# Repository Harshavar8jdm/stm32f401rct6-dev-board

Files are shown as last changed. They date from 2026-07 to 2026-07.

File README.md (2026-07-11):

# STM32F401RCT6 Development Board

A compact development board built around the STM32F401RCT6 microcontroller. The design provides access to core peripherals via standard pin headers, incorporates dedicated power plane isolation for analog stability, and includes robust ESD protection for reliable USB communication. 

## Visuals

### Schematic Diagram
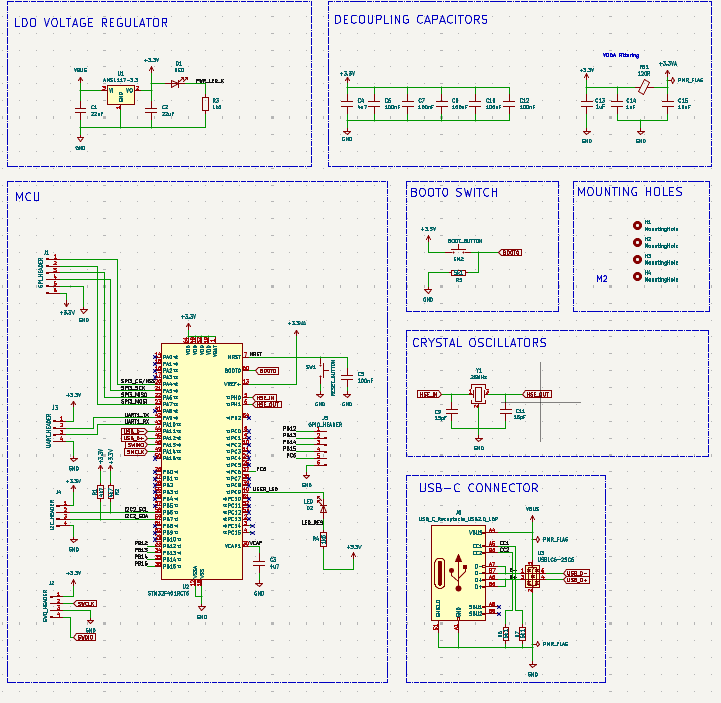
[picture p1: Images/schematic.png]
Schematic


### PCB Layout
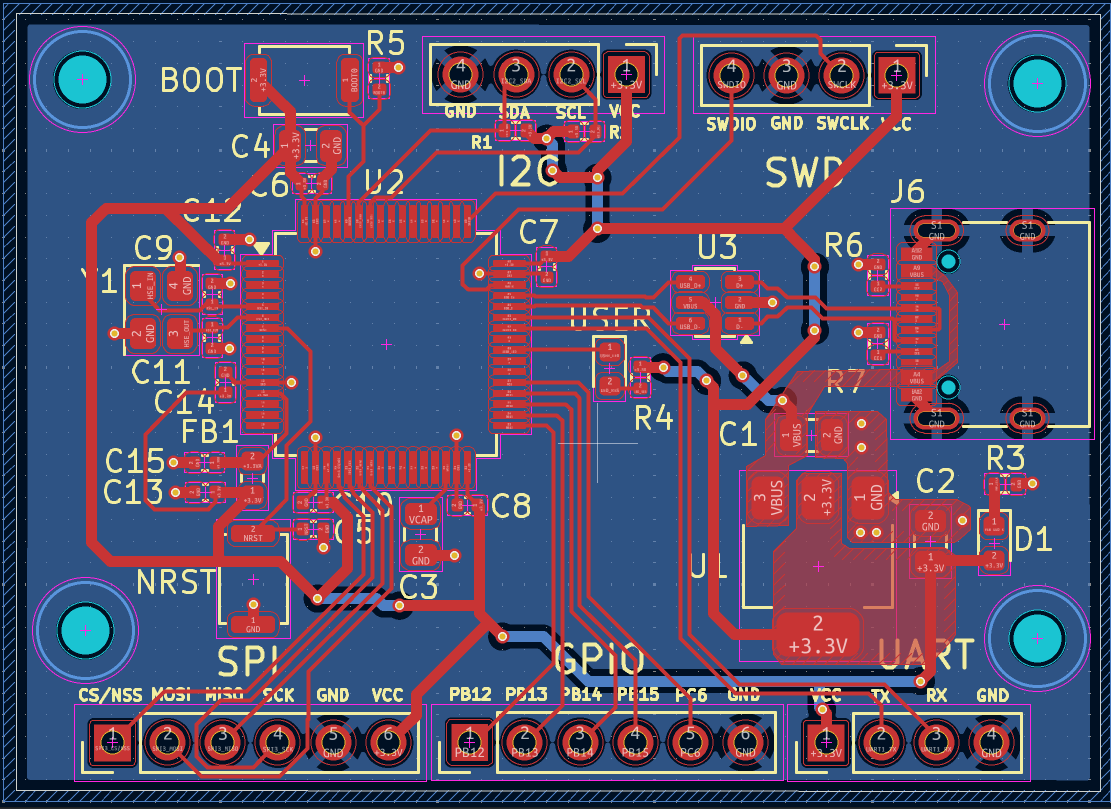
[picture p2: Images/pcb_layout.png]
PCB Layout


### 3D Renders
| Front View | Back View |
| :---: | :---: |
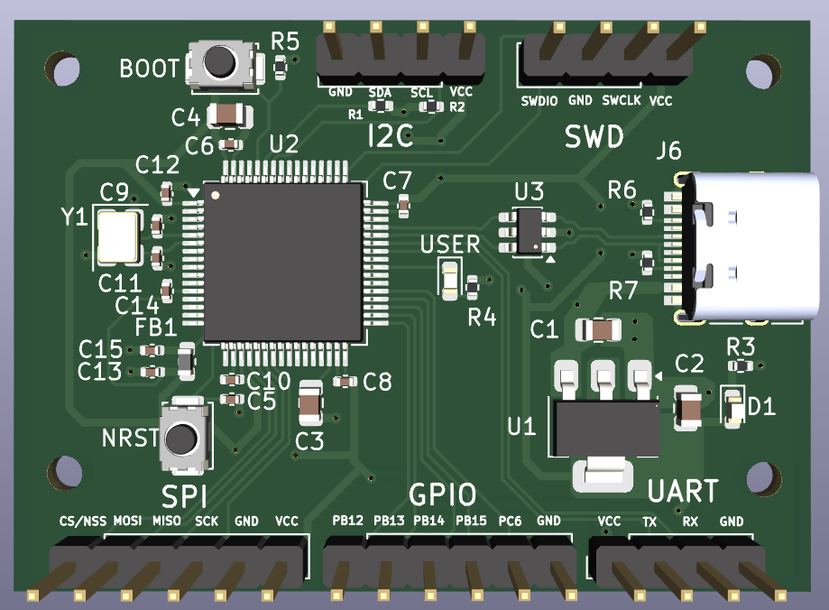
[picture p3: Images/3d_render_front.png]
3D Render Front
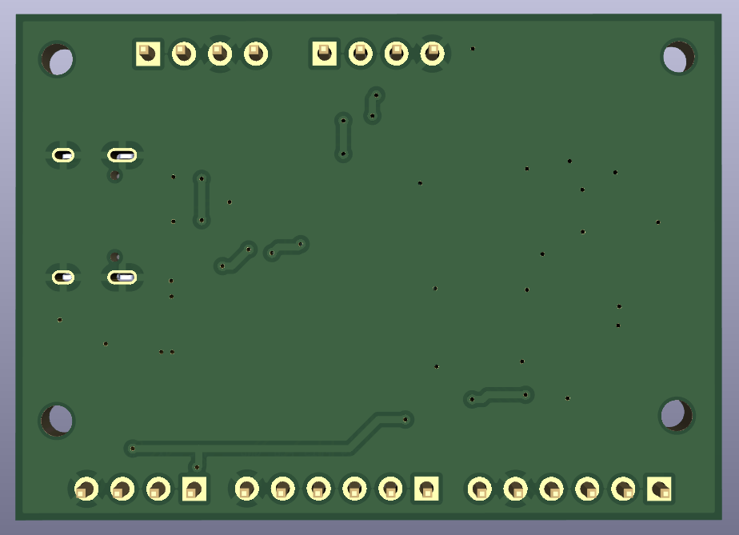
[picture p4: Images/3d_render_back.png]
3D Render Back
|  |  |

---

## Features

### 1. Core Processing & Clock System
* **Microcontroller:** STM32F401RCT6, 32-bit ARM Cortex-M4 core running up to 84 MHz.
* **High-Speed External (HSE) Clock:** $25\text{ MHz}$ crystal oscillator loop supplying the primary system and peripheral clock source.
* **Low-Speed External (LSE) Clock:** $32.768\text{ kHz}$ tuning-fork crystal providing timing for the internal Real-Time Clock (RTC).
* **Reset & Boot Controls:** Hardware reset circuitry utilizing an RC network connected to the `NRST` pin, paired with a dedicated physical push-button to pull `BOOT0` high for system bootloader entry.

### 2. Power Delivery & Noise Mitigation
* **Voltage Regulation:** AMS1117-3.3 Linear Voltage Regulator (LDO) stepping down a $5\text{V}$ input supply (via USB) to a regulated $+3.3\text{V}$ system rail, decoupled with dual $22\ \mu\text{F}$ bulk capacitors.
* **Digital Rail Decoupling:** Localized filtering network consisting of one $4.7\ \mu\text{F}$ bulk capacitor and five independent $100\text{ nF}$ capacitors dedicated to the $V_{DD}$ supply pins.
* **Analog Isolation ($+3.3\text{VA}$):** A $100\ \Omega$ (at $100\text{ MHz}$) ferrite bead creates a low-pass filter to separate the analog supply from digital switching noise, supported by dedicated $1\ \mu\text{F}$ and $100\text{ nF}$ capacitors.

### 3. Connectivity & Protection
* **USB-C Interface:** USB 2.0 downstream configuration over a physical USB-C connector using dual $5.1\text{ k}\Omega$ pulldown resistors on the `CC1` and `CC2` channels.
* **Transient Voltage Protection:** A USBLC6-2SC6 monolithic ESD protection diode array is placed directly on the `USB_D+` and `USB_D-` lines to safeguard internal transceivers against electrostatic discharge.
* **Peripheral Access:** Dedicated pin headers breaking out SPI (`SPI3`), I2C (`I2C2`), UART (`UART1`), Serial Wire Debug (`SWD`), and generic GPIOs.
* **System Status:** Physical LED indicators tracking power availability ($+3.3\text{V}$) and a user-programmable diagnostic LED linked to pin `PA0`.

---

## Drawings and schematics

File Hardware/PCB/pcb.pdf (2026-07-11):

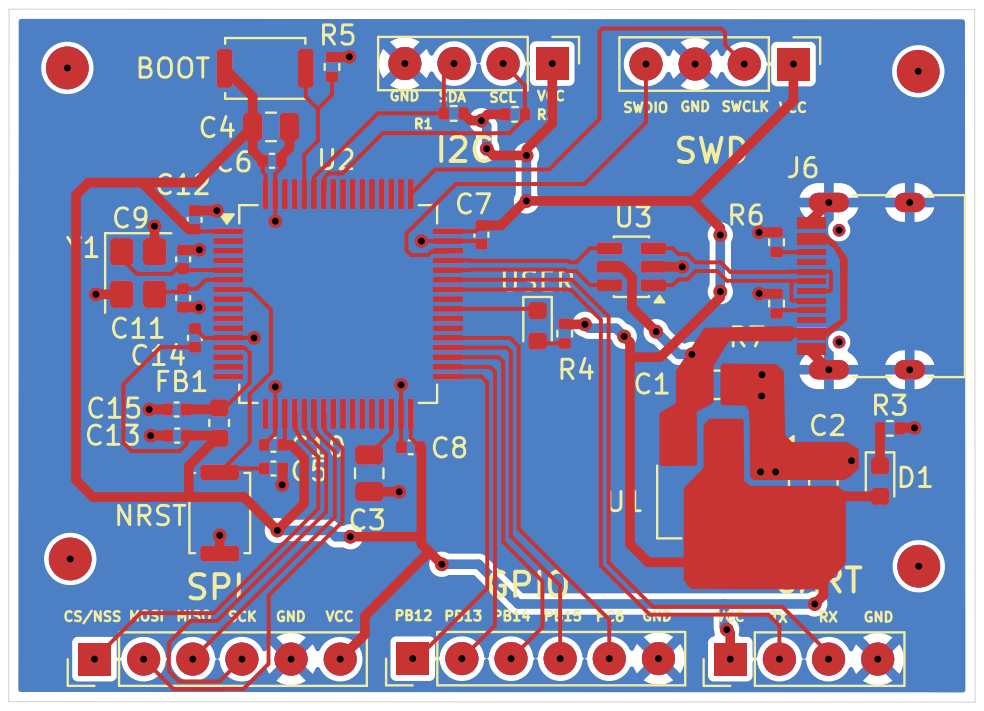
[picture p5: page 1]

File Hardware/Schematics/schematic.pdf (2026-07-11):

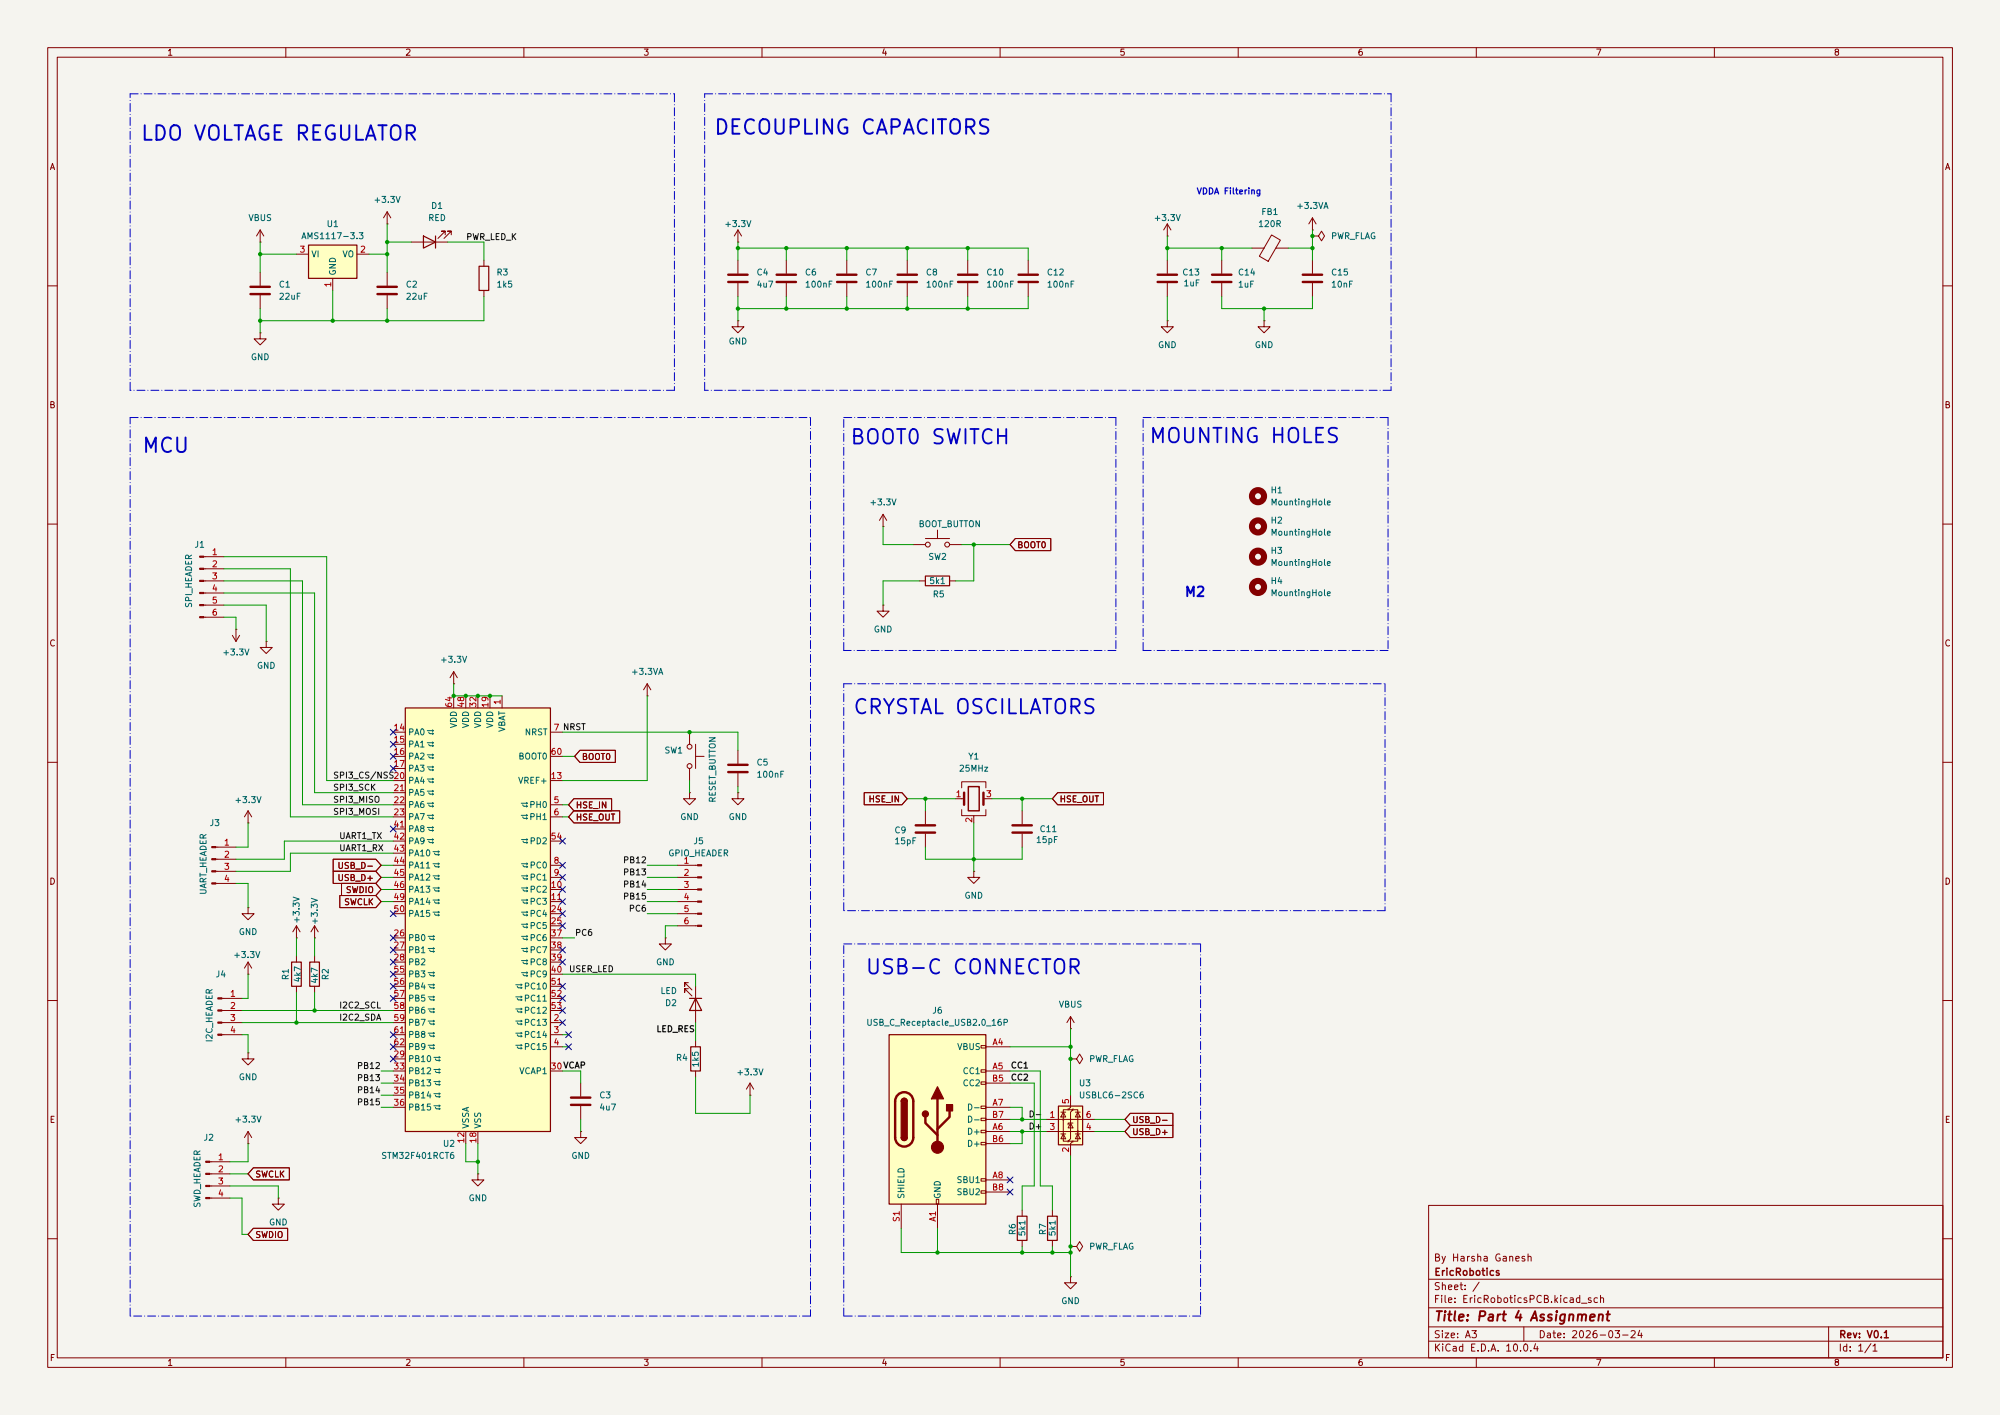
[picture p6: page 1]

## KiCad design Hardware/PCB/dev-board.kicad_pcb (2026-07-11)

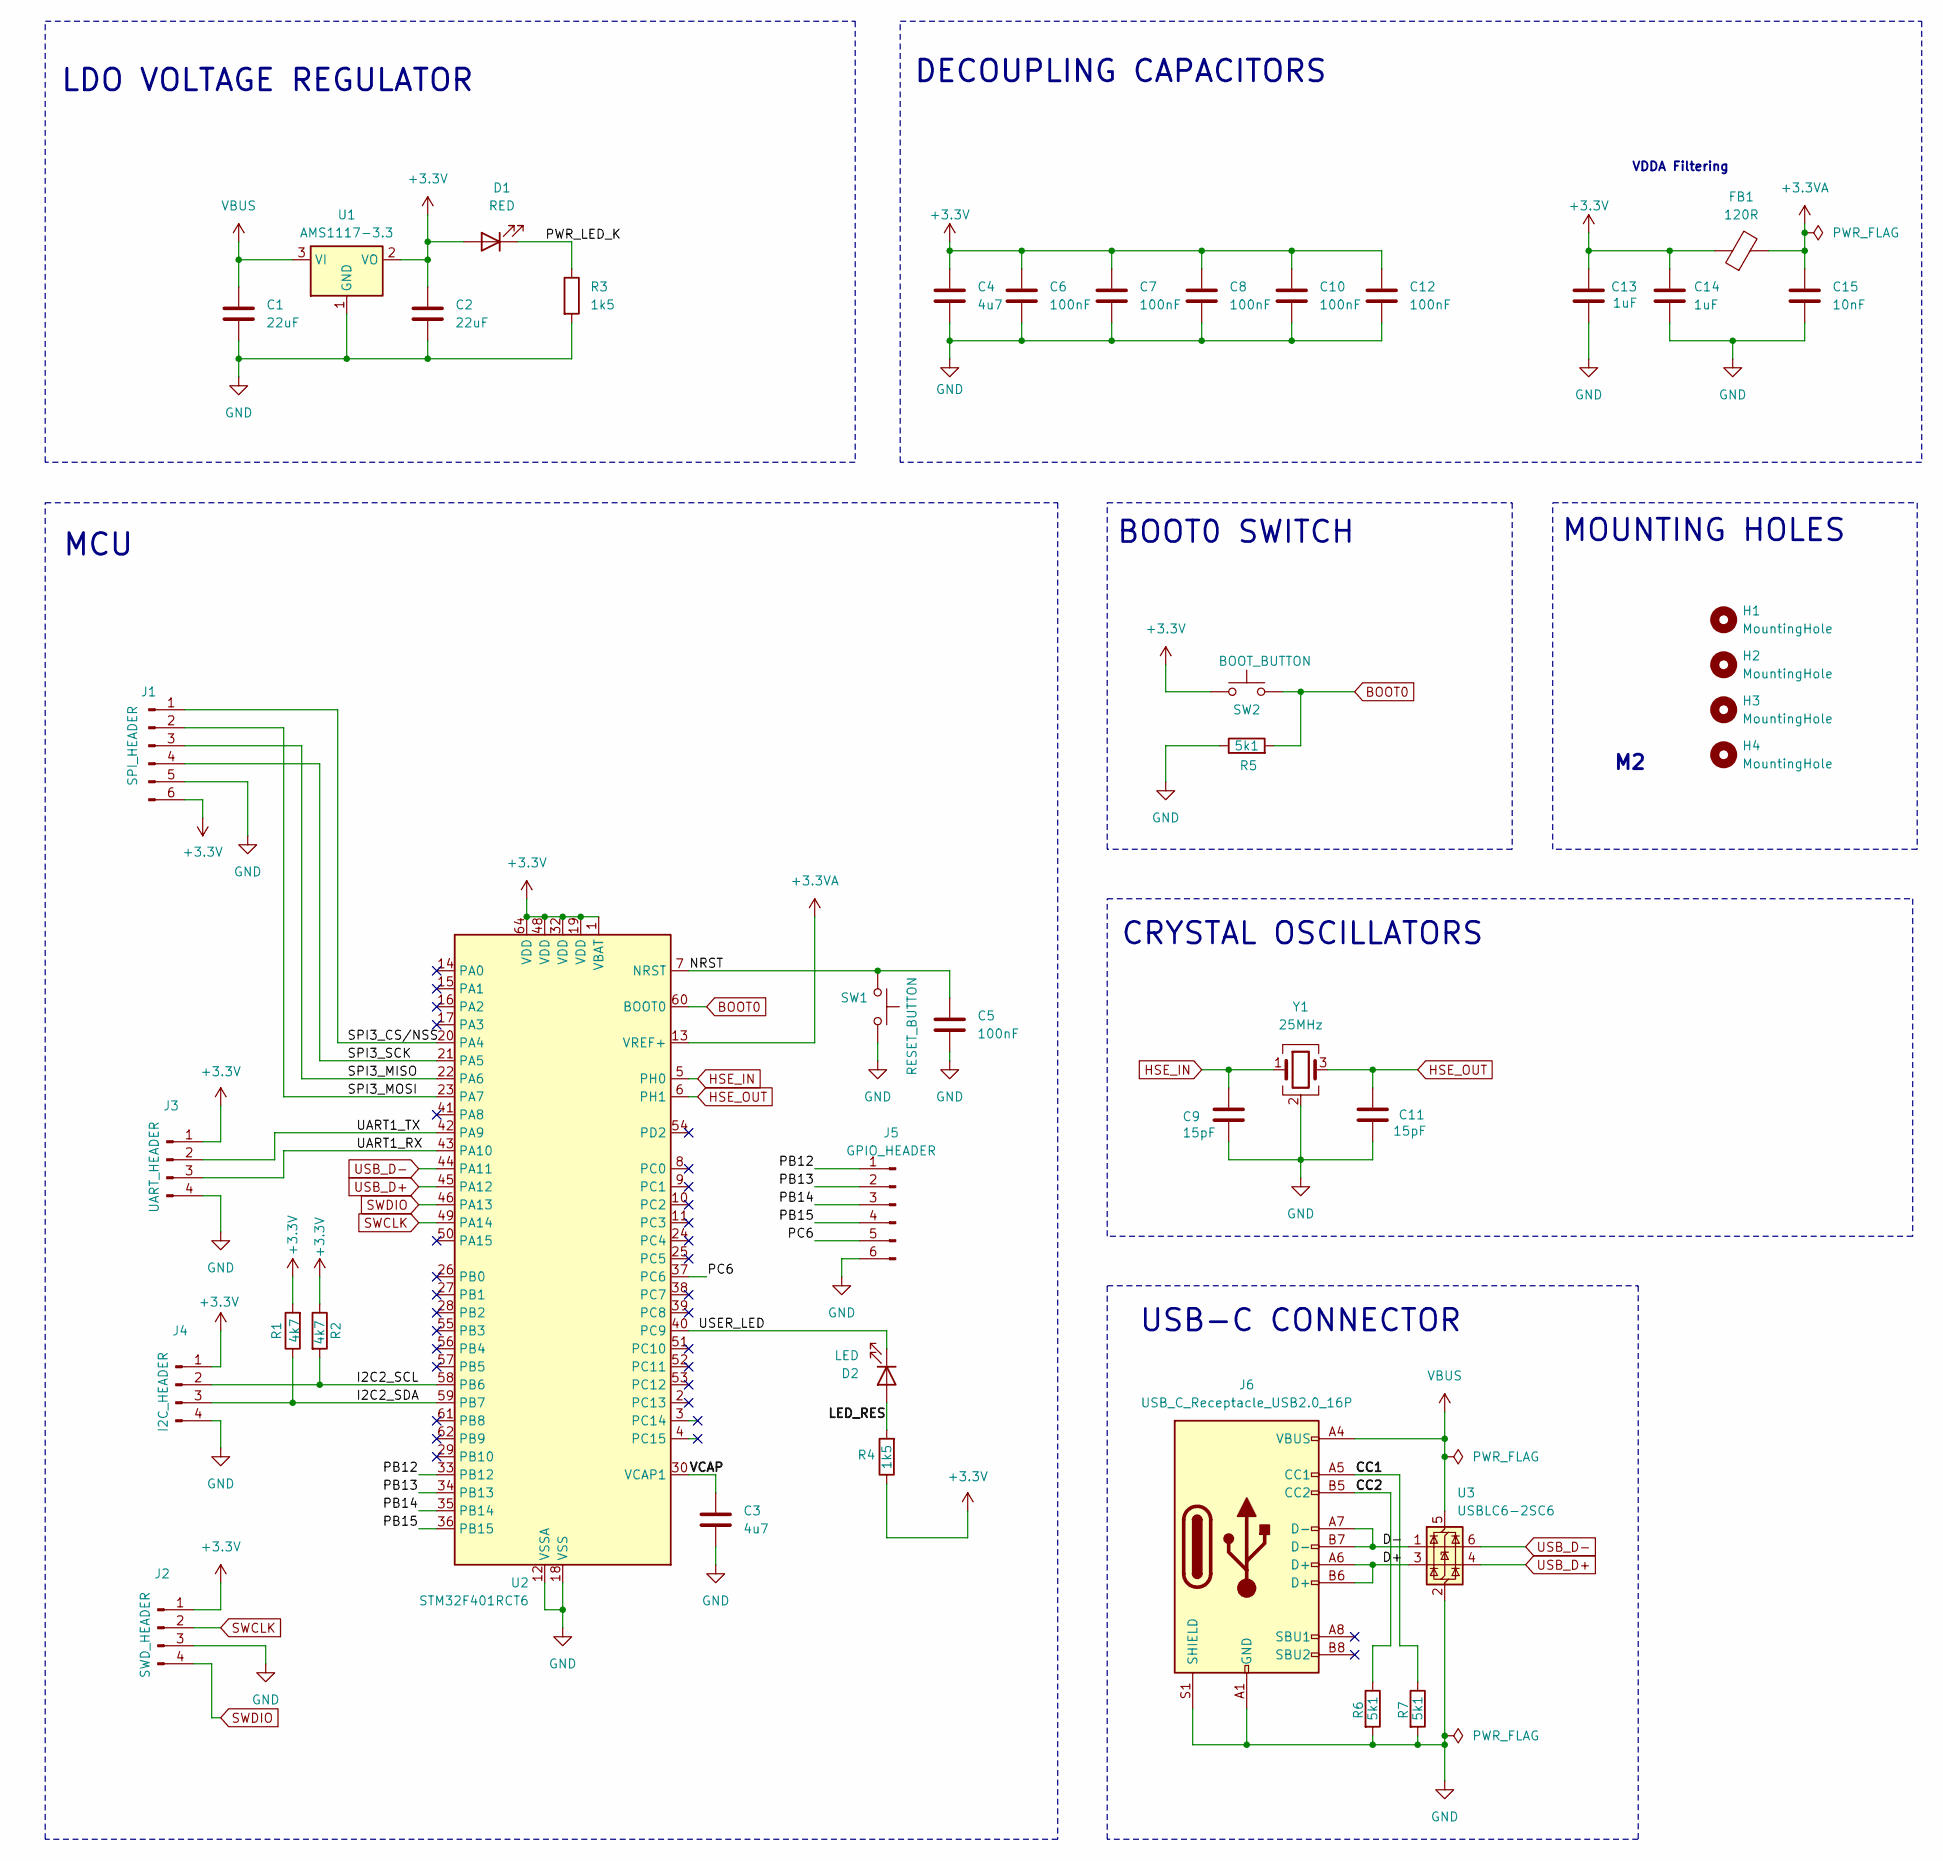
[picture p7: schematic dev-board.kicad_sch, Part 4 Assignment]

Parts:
C1, C2: 22uF; C_0805_2012Metric
C3, C4: 4u7; C_0805_2012Metric
C5, C6, C7, C8, C10, C12: 100nF; C_0402_1005Metric
C9, C11: 15pF; C_0402_1005Metric
C13, C14: 1uF; C_0402_1005Metric
C15: 10nF; C_0402_1005Metric
D1: RED; LED_0603_1608Metric
D2: LED; LED_0603_1608Metric
FB1: 120R; L_0603_1608Metric
H1, H2, H3, H4: MountingHole; MountingHole_2.2mm_M2
J1: SPI_HEADER; PinHeader_1x06_P2.54mm_Vertical
J2: SWD_HEADER; PinHeader_1x04_P2.54mm_Vertical
J3: UART_HEADER; PinHeader_1x04_P2.54mm_Vertical
J4: I2C_HEADER; PinHeader_1x04_P2.54mm_Vertical
J5: GPIO_HEADER; PinHeader_1x06_P2.54mm_Vertical
J6: USB_C_Receptacle_USB2.0_16P; USB_C_Receptacle_HRO_TYPE-C-31-M-12
R1, R2: 4k7; R_0402_1005Metric
R3, R4: 1k5; R_0402_1005Metric
R5, R6, R7: 5k1; R_0402_1005Metric
SW1: RESET_BUTTON; SW_Push_SPST_NO_Alps_SKRK
SW2: BOOT_BUTTON; SW_Push_SPST_NO_Alps_SKRK
U1: AMS1117-3.3; SOT-223-3_TabPin2
U2: STM32F401RCT6; LQFP-64_10x10mm_P0.5mm
U3: USBLC6-2SC6; SOT-23-6
Y1: 25MHz; Crystal_SMD_3225-4Pin_3.2x2.5mm

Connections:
+3.3V: C2.1, C4.1, C6.1, C7.1, C8.1, C10.1, C12.1, C13.1, C14.1, D1.2 (A), FB1.1, J1.6, J2.1, J3.1, J4.1, R1.2, R2.1, R4.1, SW2.2, U1.2 (VO), U2.1 (VBAT), U2.19 (VDD), U2.32 (VDD), U2.48 (VDD), U2.64 (VDD); also elsewhere on the board
+3.3VA: C15.1, FB1.2, U2.13 (VREF+)
/CC1: J6.A5 (CC1), R7.1
/CC2: J6.B5 (CC2), R6.1
/D+: J6.A6 (D+), J6.B6 (D+), U3.3 (I/O2)
/D-: J6.A7 (D-), J6.B7 (D-), U3.1 (I/O1)
/I2C2_SCL: J4.2, R2.2, U2.58 (PB6)
/I2C2_SDA: J4.3, R1.1, U2.59 (PB7)
/LED_RES: D2.2 (A), R4.2; also elsewhere on the board
/NRST: C5.1, SW1.2, U2.7 (NRST); also elsewhere on the board
/PB12: J5.1, U2.33 (PB12)
/PB13: J5.2, U2.34 (PB13)
/PB14: J5.3, U2.35 (PB14)
/PB15: J5.4, U2.36 (PB15)
/PC6: J5.5, U2.37 (PC6)
/PWR_LED_K: D1.1 (K), R3.1
/SPI3_CS/NSS: J1.1, U2.20 (PA4)
/SPI3_MISO: J1.3, U2.22 (PA6)
/SPI3_MOSI: J1.2, U2.23 (PA7)
/SPI3_SCK: J1.4, U2.21 (PA5)
/UART1_RX: J3.3, U2.43 (PA10)
/UART1_TX: J3.2, U2.42 (PA9)
/USER_LED: D2.1 (K), U2.40 (PC9); also elsewhere on the board
/VCAP: C3.1, U2.30 (VCAP1)
BOOT0: R5.2, SW2.1, U2.60 (BOOT0); also elsewhere on the board
GND: C1.2, C2.2, C3.2, C4.2, C5.2, C6.2, C7.2, C8.2, C9.2, C10.2, C11.2, C12.2, C13.2, C14.2, C15.2, J1.5, J2.3, J3.4, J4.4, J5.6, J6.A1 (GND), J6.A12 (GND), J6.B1 (GND), J6.B12 (GND), J6.S1 (SHIELD), R3.2, R5.1, R6.2, R7.2, SW1.1, U1.1 (GND), U2.12 (VSSA), U2.18 (VSS), U2.31 (VSS), U2.47 (VSS), U2.63 (VSS), U3.2 (GND), Y1.2 (G), Y1.4 (G); also elsewhere on the board
HSE_IN: C9.1, U2.5 (PH0), Y1.1
HSE_OUT: C11.1, U2.6 (PH1), Y1.3
SWCLK: J2.2, U2.49 (PA14)
SWDIO: J2.4, U2.46 (PA13)
USB_D+: U2.45 (PA12), U3.4 (I/O2)
USB_D-: U2.44 (PA11), U3.6 (I/O1)
VBUS: C1.1, J6.A4 (VBUS), J6.A9 (VBUS), J6.B4 (VBUS), J6.B9 (VBUS), U1.3 (VI), U3.5 (VBUS)

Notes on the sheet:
LDO VOLTAGE REGULATOR
MOUNTING HOLES
BOOT0 SWITCH
MCU
USB-C CONNECTOR
DECOUPLING CAPACITORS
CRYSTAL OSCILLATORS
VDDA Filtering

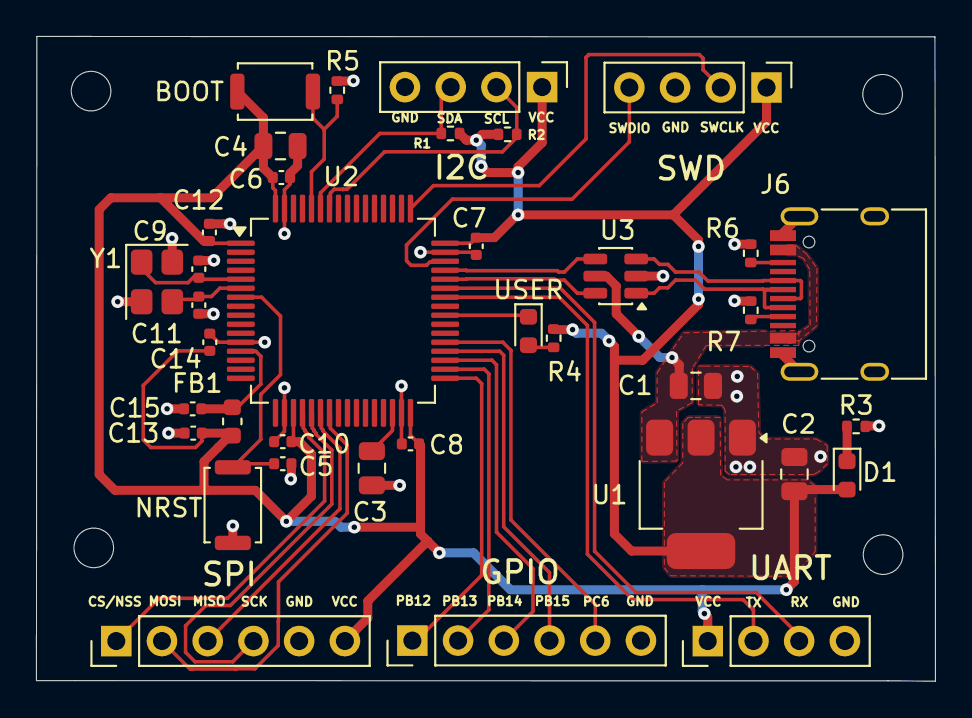
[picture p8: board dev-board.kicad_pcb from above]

Board: 2 copper layers, 49.9 x 35.8 mm, 41 parts (0 on the bottom side), 33 nets.

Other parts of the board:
BOOT: BOOT_BUTTON; SW_Push_SPST_NO_Alps_SKRK
NRST: RESET_BUTTON; SW_Push_SPST_NO_Alps_SKRK
USER: LED; LED_0603_1608Metric

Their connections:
+3.3V: BOOT.2; also elsewhere on the board
/LED_RES: USER.2 (A); also elsewhere on the board
/NRST: NRST.2; also elsewhere on the board
/USER_LED: USER.1 (K); also elsewhere on the board
BOOT0: BOOT.1; also elsewhere on the board
GND: NRST.1; also elsewhere on the board

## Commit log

2026-07-11 Add new PCB design for dev-board
    [dev-board.kicad_pcb]
2026-07-11 Update README to remove KiCad version
    Removed outdated KiCad version information from README.
